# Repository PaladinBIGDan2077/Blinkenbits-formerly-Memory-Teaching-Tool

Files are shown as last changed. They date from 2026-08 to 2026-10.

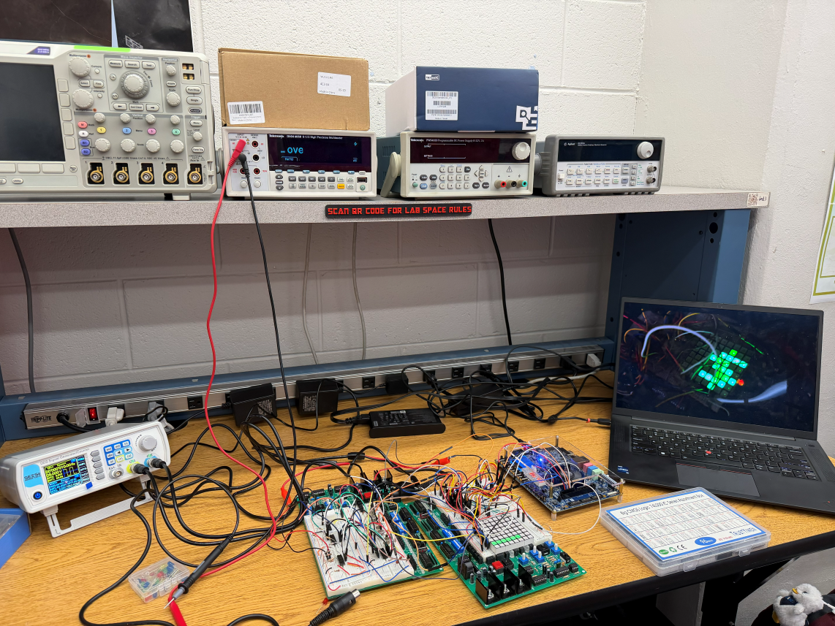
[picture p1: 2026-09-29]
hero.png

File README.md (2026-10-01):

# Project Name
WIP Title: BlinkenBits

Internal Codename: Memory Teaching Tool

# Members
Daniel J. Lomis, Computer Engineering: Chip-Scale Integration (May 2027)
dlomis1999@vt.edu

# Mentor
Professor Jason S. Thweatt

# Current Status
IN PROGRESS

# Project Overview

This project will demonstrate to the end-user how memory is used to store and read data within a computer, how changing BITs will have an effect on the output of a visualized character. While the unit itself will not be using a centralized processing unit to control the screen, instead an ASCII table will be given to insert the desired letter into each memory address, those bits will then be decoded by a character generator ROM made by Fairchild Semiconductor. The particular part is a 3257ADC from the late 1970s. The use of vintage components in this particular build helps to take away the layers of abstraction that computers now typically use in modern day technology. By simplifying the underlying hardware, this has the result of making the overall explanation of its functionality simpler. All plans were originally meant to include a set of early 1980s SRAM modules and to only develop one board; however, the scope and end goal of this project has grown to the creation of about 20 boards necesitating the switch to a more reliable supply of MM2114 SRAM Units. 

# Educational Value Added

It provides insight to how a character generator ROMs works, which were quite common in the days of early home computing. This type of technology was used in primitive computer video cards, consoles, glass teletype systems, and signage. This will lead to a further understanding of ASCII based decoding. Storage of certain bits will allow the character rom to display individual characters on an LED Matrix, which will allow the viewer to write a message on screen letter by letter. A Binary Counter will be used to scroll through memory addresses, and a buffer will be used to display the current data to write to memory, as well as entry of a specific memory address. This will be given as a either a hexadecimal readout and binary readout of the bus as well. Octal might be implemented depending on time. Since the CG ROM only needs six bits to cover the original 64 ASCII characters installed on it, the two remaining bits might be used to control the color being displayed (00 - Red, 01 - Green, 10 - Blue, 11 - Blank). The end goal is to potentially showcase 20 of these boards to a class of students (like middle-school, elementary-school) and try to recruit students into the field of Computer Engineering/Science. 

# Tasks

## Completed Tasks
 - Functional and Reliable Implementation of the 8x8 LED Matrix
 - Sourcing the proper driving logic to handle the display generation
 - Selection of appropriate memory DIPs for the project
 - Drafted initial design of character input, insert/read, using D-type Flip Flops, SR Latch, Asynchronus Clear Binary Counter with Preset-able Option and Bus Trancievers.
 - Finalized testing platform for circuit testing and implementation development
 - Testing of SR Latch as a potential input method for data (allowing the use of momentary switches)

## Remaining tasks
 - Preliminary physical development of the data portion of the data input circuit
 - Implement Memory Testing using SystemVerilog to check the operation of the MM2114
 - Develop a physical PCB prototype of the 8x8 Matrix portion of the circuit (as current implementation has a tendency to fail due to the literal rats nest of jumpers and wires being used. This will improve testing accuracy when moving on to the data input side)
 - Develop a PCB Footprint and Symbol for the 8x8 Matrix in KiCad
 - Determine the best circuit to implement the clock generation for the vertical and horizontal line drawing (must be two separate circuits), maybe PLL-based for Vertical generation or both maybe 555-based for the Horizontal generation (needs to be adjustable to center the letter)
 - Determine the best way to change colors either using relays or solid state circuits (it may need to involve 7 separate 3-direction analog multiplexers per column)

# Design Decisions

 - the board will be placed on a single PCB smaller than a sheet of standard letter paper
 - the device will be using a 16 VDC power supply going into the power connector on the board. The type of power supply and whether it will be USB-C based has yet to be determined.
 - the 3257ADC is the heart of the display readout
 - A combination of decade counters, inverters, Bipolar-Junction Transistors, 3-t0-8 decoders will be used to control the display output
 - Power Supply will likely be shielded or encased to avoid potential burns from the Voltage Regulators (potentially using the cage itself as a heatsink?)
   
# Design Misc

## 8-Bit D-type Flip Flop Demo Board
 - Developed a preliminary demo PCB (using an octal D-type Flip Flop chip) to aide in improving circuit development knowledge, and ensure a sucessful and functional build
 - Learned important methods to clock circuit design practices
   
# Steps for Documenting Your Design Process

Additions completed as I go, every 8 weeks a new presentation will be uploaded demonstrating progress on the project overall (mainly for the AMP Lab team)

# BOM + Component Cost

 - VINTAGE Fairchild 3257ADC Character Generator ROM - $16.37
 - 8X8 LED MATRIX - $10.86
 - OnSemi (Motorola) 4 x 1024 Bit SRAM Memory, two in parallel making 1K of memory - $7.99 (per chip)
 - Various 74-series logic chips, more will be added as design decisions are finalized - $9.99 (per chip)
 - PCB Generation: Prototype (8-Bit D-Type Flip Flop Display Board, practice) - $11.15
 - PCB Generation: Visual-portion Prototype - $9.99
 - PCB Generation: Final Product

# Timeline

To-be Added

# Useful Links

 - https://en.wikipedia.org/wiki/ASCII
 - https://en.wikipedia.org/wiki/7400-series_integrated_circuits
 - https://en.wikipedia.org/wiki/Character_generator
 - https://en.wikipedia.org/wiki/Transistor

# Log

To-be Added (see PowerPoints Folder)

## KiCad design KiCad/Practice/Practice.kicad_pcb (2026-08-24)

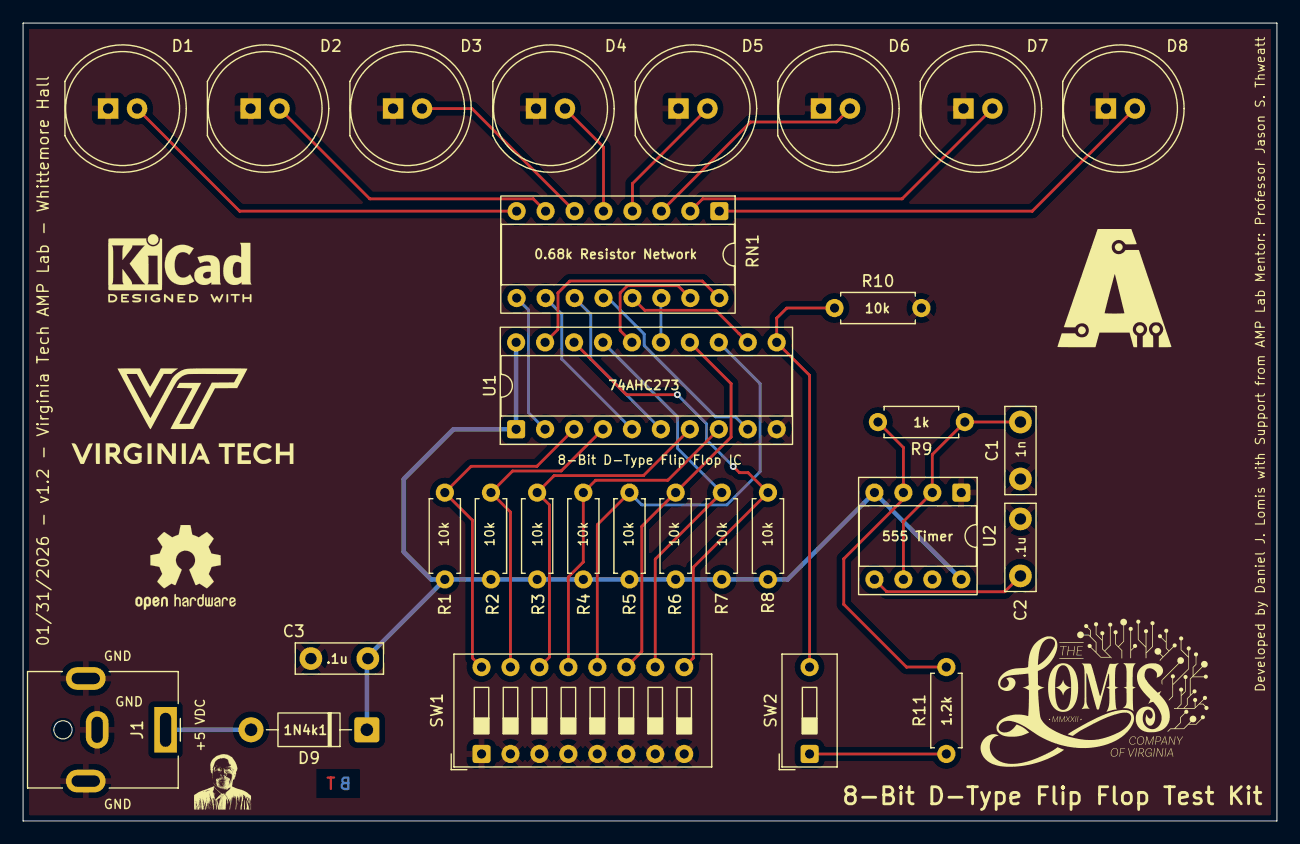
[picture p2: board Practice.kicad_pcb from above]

Board: 4 copper layers, 110.0 x 70.0 mm, 29 parts (0 on the bottom side), 32 nets.

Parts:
C1: 1n; C_Disc_D7.5mm_W2.5mm_P5.00mm
C2, C3: 100n; C_Disc_D7.5mm_W2.5mm_P5.00mm
D1, D2, D3, D4, D5, D6, D7, D8: LED; LED_D10.0mm
D9: 1N4001; D_DO-41_SOD81_P10.16mm_Horizontal
J1: Barrel_Jack_MountingPin; BarrelJack_CUI_PJ-063AH_Horizontal
R1, R2, R3, R4, R5, R6, R7, R8, R10: 10k; R_Axial_DIN0207_L6.3mm_D2.5mm_P7.62mm_Horizontal
R9: 1k; R_Axial_DIN0207_L6.3mm_D2.5mm_P7.62mm_Horizontal
R11: 1.2k; R_Axial_DIN0207_L6.3mm_D2.5mm_P7.62mm_Horizontal
RN1: R_Pack08; DIP-16_W7.62mm_Socket
SW1: SW_DIP_x08; SW_DIP_SPSTx08_Slide_9.78x22.5mm_W7.62mm_P2.54mm
SW2: SW_DIP_x01; SW_DIP_SPSTx01_Slide_9.78x4.72mm_W7.62mm_P2.54mm
U1: 74AHC273; DIP-20_W7.62mm_Socket
U2: ICM7555xP; DIP-8_W7.62mm_Socket

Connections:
+5V: C3.1, D9.1 (K), R1.1, R2.1, R3.1, R4.1, R5.1, R6.1, R7.1, R8.1, U1.1 (~Mr), U1.20 (VCC), U2.4 (R), U2.8 (VCC)
GND: C1.1, C2.2, C3.2, D1.1 (K), D2.1 (K), D3.1 (K), D4.1 (K), D5.1 (K), D6.1 (K), D7.1 (K), D8.1 (K), J1.2, J1.MP (MountPin), R10.2, SW1.1, SW1.2, SW1.3, SW1.4, SW1.5, SW1.6, SW1.7, SW1.8, U1.10 (GND), U2.1 (GND)
unnamed: D1.2 (A), RN1.8 (R8.1)
unnamed: D2.2 (A), RN1.7 (R7.1)
unnamed: D3.2 (A), RN1.6 (R6.1)
unnamed: D4.2 (A), RN1.5 (R5.1)
unnamed: D5.2 (A), RN1.4 (R4.1)
unnamed: D6.2 (A), RN1.3 (R3.1)
unnamed: D7.2 (A), RN1.2 (R2.1)
unnamed: D8.2 (A), RN1.1 (R1.1)
unnamed: D9.2 (A), J1.1
unnamed: R11.1, SW2.1
unnamed: RN1.16 (R1.2), U1.19 (Q7)
unnamed: RN1.15 (R2.2), U1.16 (Q6)
unnamed: RN1.14 (R3.2), U1.15 (Q5)
unnamed: RN1.13 (R4.2), U1.12 (Q4)
unnamed: RN1.12 (R5.2), U1.9 (Q3)
unnamed: RN1.11 (R6.2), U1.6 (Q2)
unnamed: RN1.10 (R7.2), U1.5 (Q1)
unnamed: RN1.9 (R8.2), U1.2 (Q0)
unnamed: R10.1, SW2.2, U1.11 (Cp)
unnamed: R1.2, SW1.16, U1.3 (D0)
unnamed: R2.2, SW1.15, U1.4 (D1)
unnamed: R3.2, SW1.14, U1.7 (D2)
unnamed: R4.2, SW1.13, U1.8 (D3)
unnamed: R5.2, SW1.12, U1.13 (D4)
unnamed: R6.2, SW1.11, U1.14 (D5)
unnamed: R7.2, SW1.10, U1.17 (D6)
unnamed: R8.2, SW1.9, U1.18 (D7)
unnamed: C2.1, U2.5 (CV)
unnamed: R9.2, R11.2, U2.3 (Q)
unnamed: C1.2, R9.1, U2.2 (TR), U2.6 (THR)

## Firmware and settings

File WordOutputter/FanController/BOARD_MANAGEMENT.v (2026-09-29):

module BOARD_MANAGEMENT (	
    output reg I2C_READY,
    input clk_50,
    input reset_n,

    // device i2c interface
    inout I2C_SCL,
    inout I2C_SDA,

    // board info and control
    output signed [15:0] FPGA_Temperature,  // unit: C
    output signed[15:0] Board_Temperature,  // unit: C
    output signed[15:0] Board2_Temperature, // unit: C
    output [15:0] Fan_Speed,                // unit: RPM

    input         Auto_Fan_Speed,      // 1: enable audo speed control.0: user specify fan speed
    input  [15:0] Set_Fan_Speed  ,     // used when Auto_Fan_Speedis low

	
//-------------------------

	//FAN IC      
	output reg [ 7:0] TACH0, 
	output reg [ 7:0] TACH1, 
	output reg [ 7:0] DAC,
	output reg [ 7:0] ALARM,
		
	//--TEMP
	output            TEMP_BUSY, 
	output reg 			TEMP_VALID,	
	//442A
	output reg signed [ 7:0] A_LOCT1_H,
	output reg signed [ 7:0] A_REMT1_H,
	output reg signed [ 7:0] A_REMT2_H,
	output reg [ 7:0] A_STATUS,
	output reg [ 7:0] A_MFG_ID,
	output reg [ 7:0] A_DEV_ID,
			
		
	//--TEST -- 
   output reg       I2C_LO0P,	
	output reg [7:0] SLAVE_ADDR , 
   output reg [7:0] ST ,
   output reg [7:0] CNT,
	output reg [7:0] WCNT,
   output reg [7:0] W_WORD_DATA,
   output reg [7:0] W_POINTER_REG,
	
	output           W_WORD_END ,
   output reg       W_WORD_GO ,	
   output     [7:0] R_DATA,
	input            BUSY_GO_HI 

);


wire [7:0] user_ktach;
assign   user_ktach =  ((992 * KSCALE ) / (Set_Fan_Speed/60) ) - 1;

//---- output to MAX6650 KTACH ; 
wire      [ 7:0] KTACH;
assign  KTACH = Auto_Fan_Speed? auto_ktach :user_ktach ; 


//-----MAX Temperature ( FPGA, Board , Board2 ) to Auto fan --- 
reg signed[7:0] AutoFan_temp=40 ; 
always @ (posedge CLK_400K or negedge reset_n )
begin
	if (~reset_n)
		AutoFan_temp <= 40;
	else begin 
	        if ((FPGA_Temperature   >=Board_Temperature ) &&  (FPGA_Temperature   >= Board2_Temperature)) AutoFan_temp   <= FPGA_Temperature;
	   else if ((Board_Temperature  >=FPGA_Temperature  ) &&  (Board_Temperature  >= Board2_Temperature)) AutoFan_temp   <= Board_Temperature;
	   else if ((Board2_Temperature >=FPGA_Temperature  ) &&  (Board2_Temperature >= Board_Temperature )) AutoFan_temp   <= Board2_Temperature;
	   
	end  
end

//--------Auto FAN -----------------
wire invalid_temp ; 
wire [7:0]auto_ktach ;           
AutoFan AutoFan_inst(
	.clk         ( CLK_400K     ),
	.reset_n     ( reset_n      ),
	.temp_fpga   ( AutoFan_temp ),
	.fan_ktach   ( auto_ktach   ) ,
	.invalid_temp(invalid_temp  ) 
);
//----------------------------------------------------



/////

//---- output FAN speed
assign Fan_Speed   = 60 * TACH0  ;   //rpm  

//---- output FPGA temperature
assign FPGA_Temperature = A_REMT1_H ; 

//---- output BOARD temperature
assign  Board_Temperature = A_LOCT1_H ; 

//---- output BOARD2 temperature
assign  Board2_Temperature = A_REMT2_H ; 





//----400KHZ generater-----
wire CLK_400K;
CLOCKMEM CLOCKMEM_inst2(  .RESET_n(1), .CLK    (clk_50),.CLK_FREQ(125) ,.CK_1HZ (CLK_400K)) ;

//=======================================================
//  WIRE /REGISETER 
//=======================================================

//--I2C Main Controller--- 
reg  [31:0] DELY;

//-----I2C-BUS-I/O----
wire        SDAO;
wire        SCLO;
wire        W_WORD_SCL; 
wire        W_WORD_SDAO;  
wire        W_POINTER_SCL; 
wire        W_POINTER_END; 
reg         W_POINTER_GO;
wire        W_POINTER_SDAO; 
wire        R_SCL; 
wire        R_END; 
reg         R_GO; 
wire        R_SDAO;  

//=======================================================
//  Parameter  
//=======================================================
// I2C  W/R NUMBER 
parameter    WRITE_MAX      = 10; 
parameter    READ_MAX       = 10; 
    
//--- Temperature-Sensor IC (TMP442) Register -----    
parameter    SLAVE_ADDR_TA = 8'h98;
 
parameter    PA_CONF1      = 8'h09;    // Write configuration byte
parameter    PA_CONF2      = 8'h0a;    // Write configuration byte
parameter    PA_RATE       = 8'h0B;    // Write conversion rate byte
parameter    PA_MFG_ID     = 8'hFE;    //55h
parameter    PA_DEV_ID     = 8'hFF;    //42h
parameter    PA_LOCT1_H    = 8'h00;    //Read local temperature
parameter    PA_LOCT1_L    = 8'h10;    //Read local temperature
parameter    PA_REMT1_H    = 8'h01;    //Read remote temperature: returns latest temperature
parameter    PA_REMT1_L    = 8'h11;    //Read remote temperature: returns latest temperature
parameter    PA_REMT2_H    = 8'h02;    //Read remote temperature: returns latest temperature
parameter    PA_REMT2_L    = 8'h12;    //Read remote temperature: returns latest temperature
parameter    PA_STATUS     = 8'h08;    //Read status byte (flags, busy signal)
parameter    PA_SFRESET    = 8'hFC;    //oftware Reset(4

	 
//--- Fan IC (MAX6650) Register ----- 
//slave address   
parameter    SLAVE_ADDR_F   = 8'h90;
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

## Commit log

2026-08-24 Preliminary CAD Design Selected
    [Memory-Teaching-Tool.kicad_pcb, Memory-Teaching-Tool.kicad_sch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]
2026-10-01 Revise README with project updates and details
    Updated project details, tasks, design decisions, and BOM in README.
